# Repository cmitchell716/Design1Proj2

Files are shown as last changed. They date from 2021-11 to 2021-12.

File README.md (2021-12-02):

# Design1Proj2
This repository holds the source code for ECEN 4013 Group 2 Project 2.
The PCB and Case directories hold the files required for each component respectively. 
The headers directory have the modified header files in order to save memory.
Sketches hold all code run on the arduino, project_full is the final sketch used in the 
demonstration. All others test individual components or other related activities.

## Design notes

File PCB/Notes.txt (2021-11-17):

Notes on PCB

1. Cut bottom trace on Net (A1-Pad8) between via and Pin 8 on Arudino
2. Connected power switch between, Aux2 pin 1 and Pin 8 of Arudino

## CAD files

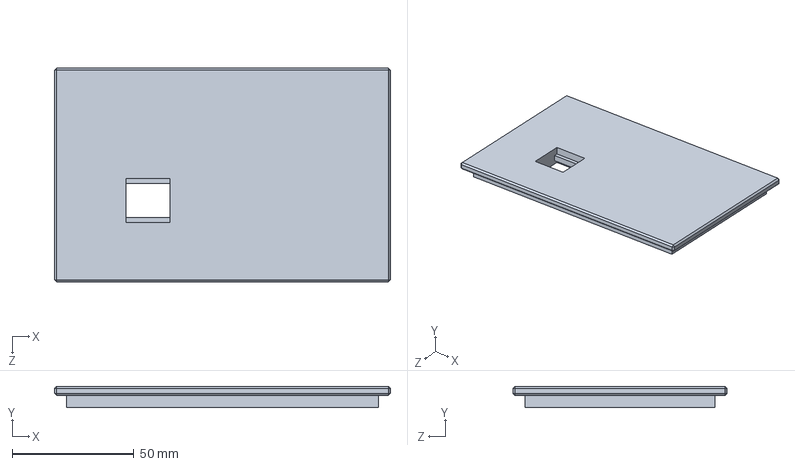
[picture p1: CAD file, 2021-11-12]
Case/Solid Works/main cover.sldprt
138.0 x 8.81 x 88.0 mm

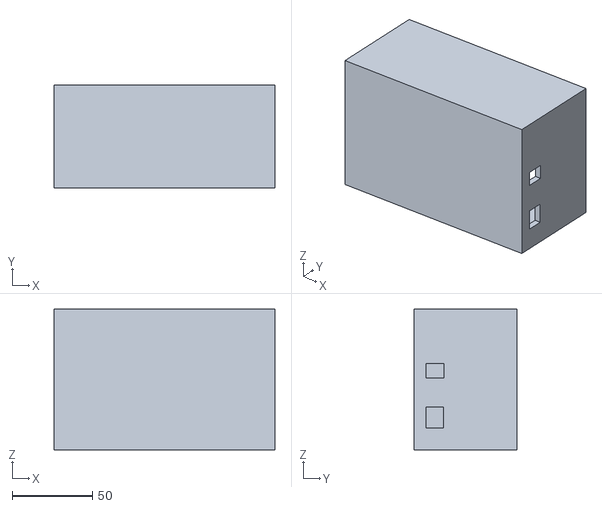
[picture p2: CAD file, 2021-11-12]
Case/STL Files/main.STL
138.0 x 64.1 x 88.0

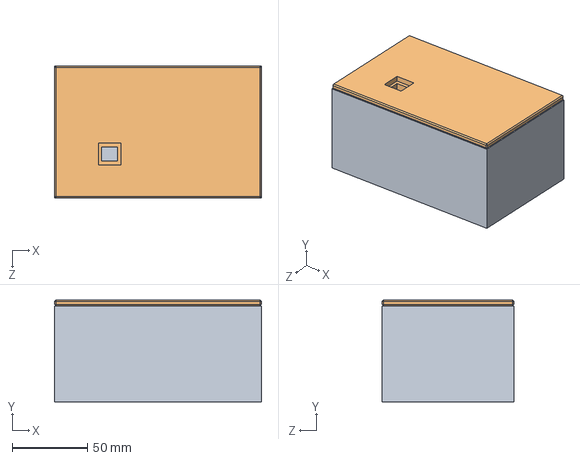
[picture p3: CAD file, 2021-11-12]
Case/Solid Works/simple box enclosure.sldasm
138.0 x 67.9 x 88.0 mm
main
main cover

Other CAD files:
Case/Solid Works/main.sldprt
Case/STL Files/main cover.STL

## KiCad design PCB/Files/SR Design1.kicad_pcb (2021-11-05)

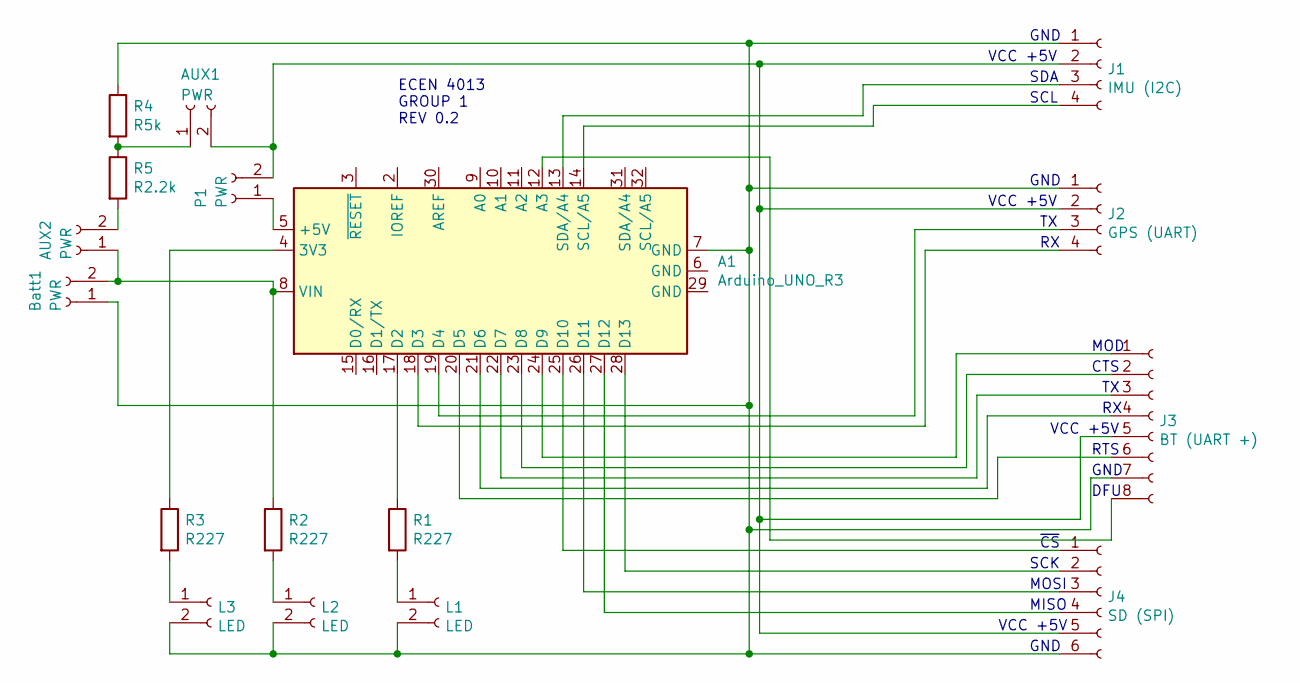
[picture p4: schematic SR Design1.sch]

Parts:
A1: Arduino_UNO_R3
AUX1, AUX2: PWR; SolderWire-0.1sqmm_1x02_P3.6mm_D0.4mm_OD1mm
Batt1: PWR; JST_XH_B2B-XH-A_1x02_P2.50mm_Vertical
J1: IMU (I2C); PinHeader_1x04_P2.00mm_Horizontal
J2: GPS (UART); PinHeader_1x04_P2.00mm_Horizontal
J3: BT (UART +); PinSocket_1x08_P2.54mm_Vertical
J4: SD (SPI); PinSocket_1x06_P2.54mm_Horizontal
L1, L2, L3: LED; SolderWire-0.1sqmm_1x02_P3.6mm_D0.4mm_OD1mm
P1: PWR; SolderWire-0.1sqmm_1x02_P3.6mm_D0.4mm_OD1mm
R1, R2, R3: R227; R_Axial_DIN0207_L6.3mm_D2.5mm_P10.16mm_Horizontal
R4: R5k; R_Axial_DIN0207_L6.3mm_D2.5mm_P10.16mm_Horizontal
R5: R2.2k; R_Axial_DIN0207_L6.3mm_D2.5mm_P10.16mm_Horizontal

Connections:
unnamed: A1.4 (3V3), R3.1
unnamed: A1.5 (+5V), P1.1
unnamed: A1.7 (GND), Batt1.1, J1.1, J2.1, J3.7, J4.6, L1.2, L2.2, L3.2, R4.1
unnamed: A1.8 (VIN), AUX2.1, Batt1.2, R2.1
unnamed: A1.12 (A3), J3.8
unnamed: A1.13 (SDA/A4), J1.3
unnamed: A1.14 (SCL/A5), J1.4
unnamed: A1.17 (D2), R1.1
unnamed: A1.18 (D3), J2.4
unnamed: A1.19 (D4), J2.3
unnamed: A1.20 (D5), J3.6
unnamed: A1.21 (D6), J3.4
unnamed: A1.22 (D7), J3.3
unnamed: A1.23 (D8), J3.2
unnamed: A1.24 (D9), J3.1
unnamed: A1.25 (D10), J4.1
unnamed: A1.26 (D11), J4.3
unnamed: A1.27 (D12), J4.4
unnamed: A1.28 (D13), J4.2
unnamed: AUX1.1, R4.2, R5.1
unnamed: AUX1.2, J1.2, J2.2, J3.5, J4.5, P1.2
unnamed: AUX2.2, R5.2
unnamed: L1.1, R1.2
unnamed: L2.1, R2.2
unnamed: L3.1, R3.2

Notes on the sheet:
GND
VCC +5V
SDA
SCL
SCK
MOSI
MISO
~CS
ECEN 4013 GROUP 1 REV 0.2
RTS
CTS
MOD
DFU

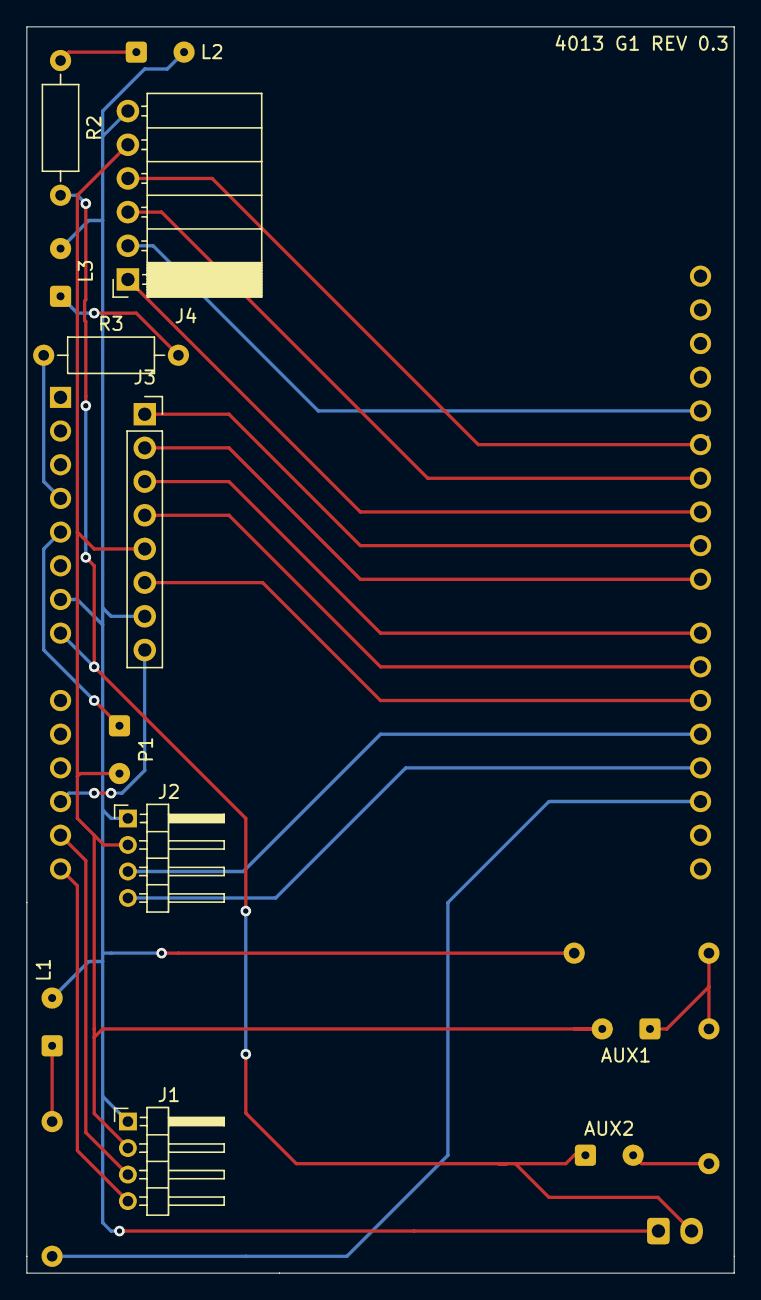
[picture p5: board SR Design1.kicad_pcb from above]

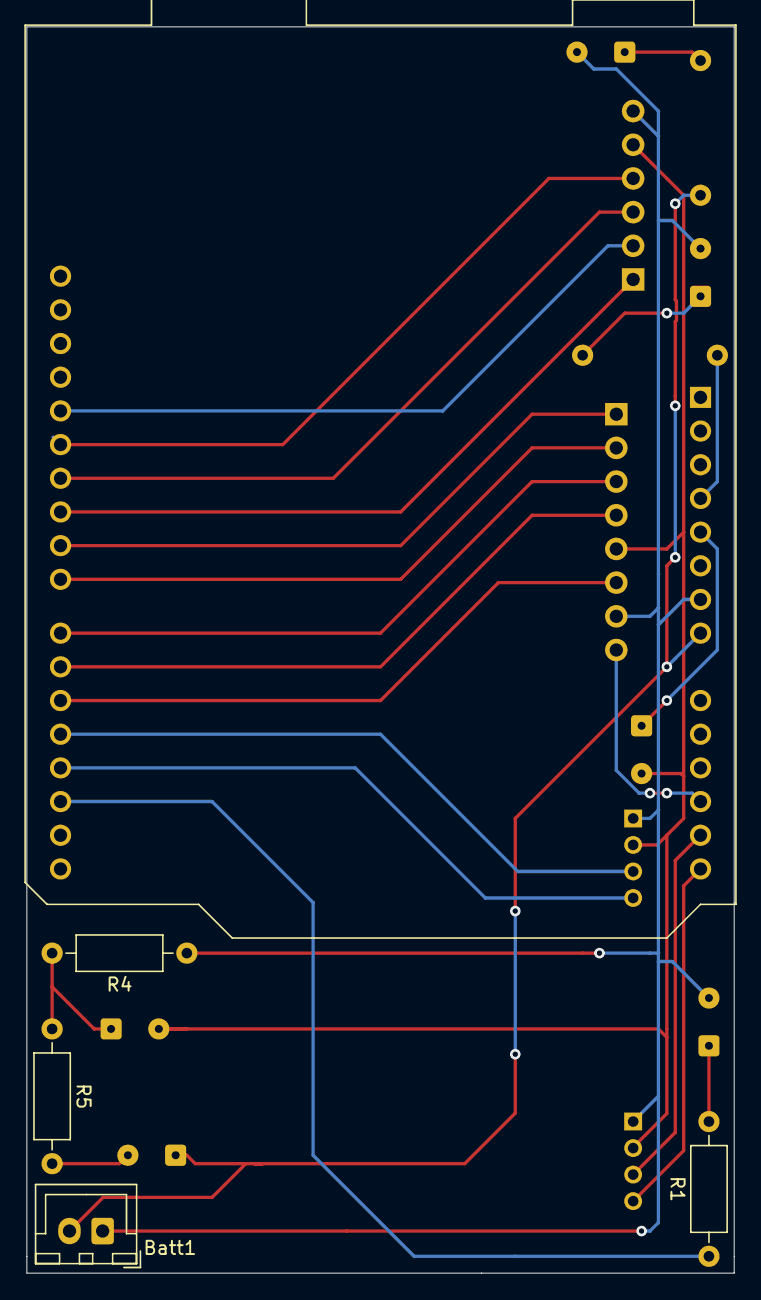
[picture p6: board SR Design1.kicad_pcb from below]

Board: 2 copper layers, 53.3 x 94.0 mm, 17 parts (5 on the bottom side), 25 nets.

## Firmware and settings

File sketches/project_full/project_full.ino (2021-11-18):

#include "C:\Users\cmitc\Documents\SeniorDesign1\Project2\repo\headers\MPU9250.h" //must change this line to location on your machine
#include <Wire.h>
#include <SoftwareSerial.h>
#include <TinyGPS_stripped.h>
#include <SPI.h>
#include <SdFat.h>
#include "Adafruit_BLE.h"
#include "Adafruit_BluefruitLE_UART.h"


TinyGPS gps;
SoftwareSerial ss(3, 4);
MPU9250 mpu;
SdFat sd;
SdFile myFile;
SoftwareSerial bluefruitSS = SoftwareSerial(7, 6);
Adafruit_BluefruitLE_UART ble(bluefruitSS, 9, 8, -1);
boolean newGPS = false;
boolean newIMU = false;
boolean SDavailable = false;
short printBle = 5;
boolean GPSlock = false;
unsigned long outputTimer;
const char filename[] = "out.csv"; 


void setup() {
  Serial.begin(9600);
  ss.begin(9600);
  Wire.begin();
  delay(2000);
  pinMode(2, OUTPUT);

  if (mpu.setup(0x68)) {  
    //mpu.setAccBias(36.19, 3.86, 54.43);
    //mpu.setGyroBias(-1.20, 1.95, -0.08);
    //mpu.setMagBias(128.27, -144.56, -176.65);
    //mpu.setMagScale(1.18, 1.03, 0.85);
    //mpu.setMagneticDeclination(3.08);
   }
  

  SDavailable = sd.begin(10, SPI_HALF_SPEED);
  if(SDavailable){
    create_file();
  }
  
  if ( !ble.begin() )
  {
    Serial.println(F("Couldn't find Bluefruit, make sure it's in CoMmanD mode & check wiring?"));
  }
  else{
    ble.echo(false);
    ble.setMode(BLUEFRUIT_MODE_DATA);
  }
  
   //SDavailable = false;
  outputTimer = millis();
}

void loop() {
  
  if (mpu.available()) {
        mpu.update_accel_gyro();
        mpu.update_mag();
        newIMU = true;
  }
  

  ss.listen();
  for (unsigned long start = millis(); millis() - start < 5;)
  {
    while (ss.available())
    {
      char c = ss.read();
      if (gps.encode(c))  
        newGPS = true;
    }
  }

  if(GPSlock){
    digitalWrite(2, HIGH);
  }
  else digitalWrite(2, LOW);
  
  if((newIMU && newGPS) || (millis() - outputTimer > 2000)) {
    print_IMU_measurements();
    print_GPS_measurements();
    outputTimer = millis();
    if(printBle == 10){
      printBle = 0;
    }
    else printBle++;
    if(newGPS){
      GPSlock = true;
    }
    else GPSlock = false;
    newGPS = false;
    newIMU = false;
  }
  
}

void create_file(){
  if (myFile.open(filename, O_WRITE | O_CREAT | O_TRUNC)) {
    delay(100);
    myFile.println(F("\"AccX\",\"AccY\",\"AccZ\",\"MagX\",\"MagY\",\"MagZ\",\"GyrX\",\"GyrY\",\"GyrZ\",\"Lat\",\"Lon\",\"Alt\",\"Sat\""));
  }
  myFile.close();
}


void print_IMU_measurements() {
  if(newIMU){
    Serial.print(F("Acc XYZ: "));
    Serial.print(mpu.getAccX(), 2);
    Serial.print(F(", "));
    Serial.print(mpu.getAccY(), 2);
    Serial.print(F(", "));
    Serial.print(mpu.getAccZ(), 2);
    Serial.print(F("  "));
    Serial.print(F("Mag XYZ: "));
    Serial.print(mpu.getMagX(), 2);
    Serial.print(F(", "));
    Serial.print(mpu.getMagY(), 2);
    Serial.print(F(", "));
    Serial.print(mpu.getMagZ(), 2);
    Serial.print(F(", "));
    Serial.print(F("Gyro XYZ: "));
    Serial.print(mpu.getGyroX(), 2);
    Serial.print(F(", "));
    Serial.print(mpu.getGyroY(), 2);
    Serial.print(F(", "));
    Serial.println(mpu.getGyroZ(), 2);

    if(printBle == 10){
      ble.print(F("Acc XYZ: "));
      ble.print(mpu.getAccX(), 2);
      ble.print(F(", "));
      ble.print(mpu.getAccY(), 2);
      ble.print(F(", "));
      ble.print(mpu.getAccZ(), 2);
      ble.print(F("  "));
      ble.print(F("Mag XYZ: "));
      ble.print(mpu.getMagX(), 2);
      ble.print(F(", "));
      ble.print(mpu.getMagY(), 2);
      ble.print(F(", "));
      ble.print(mpu.getMagZ(), 2);
      ble.print(F(", "));
      ble.print(F("Gyro XYZ: "));
      ble.print(mpu.getGyroX(), 2);
      ble.print(F(", "));
      ble.print(mpu.getGyroY(), 2);
      ble.print(F(", "));
      ble.println(mpu.getGyroZ(), 2);
    }

    if(SDavailable){      
      myFile.open(filename, O_WRITE | O_AT_END);
      myFile.print(F("\""));
      myFile.print(mpu.getAccX(), 2);
      myFile.print(F("\",\""));
      myFile.print(mpu.getAccY(), 2);
      myFile.print(F("\",\""));
      myFile.print(mpu.getAccZ(), 2);
      myFile.print(F("\",\""));
      myFile.print(mpu.getMagX(), 2);
      myFile.print(F("\",\""));
      myFile.print(mpu.getMagY(), 2);
      myFile.print(F("\",\""));
      myFile.print(mpu.getMagZ(), 2);
      myFile.print(F("\",\""));
      myFile.print(mpu.getGyroX(), 2);
      myFile.print(F("\",\""));
      myFile.print(mpu.getGyroY(), 2);
      myFile.print(F("\",\""));
      myFile.print(mpu.getGyroZ(), 2);
      myFile.print(F("\",\""));
      myFile.close();     
    }
    
  }
  else{
    Serial.println(F("No IMU data"));
    if(printBle == 10){
      ble.println(F("No IMU data"));
    }
    if(SDavailable){      
      myFile.open(filename, O_WRITE | O_AT_END);
      myFile.print(F("\"N/D\",\"N/D\",\"N/D\",\"N/D\",\"N/D\",\"N/D\",\"N/D\",\"N/D\",\"N/D\","));
      myFile.close();     
    }    
  }    
}

void print_GPS_measurements() {
  if(newGPS){
    float flat, flon;
    int alt, sat;
    alt = gps.altitude();
    sat = gps.satellites();
    gps.f_get_position(&flat, &flon );
    Serial.print(F("LAT="));
    Serial.print(flat, 6);
    Serial.print(F(" LON="));
    Serial.print(flon, 6);
    Serial.print(F(" ALT="));
    Serial.print(alt);
    Serial.print(F(" SAT="));
    Serial.println(sat);
  
    
    if(printBle == 10){
      ble.print(F("LAT="));
      ble.print(flat, 6);
      ble.print(F(" LON="));
      ble.print(flon, 6);
      ble.print(F(" ALT="));
      ble.print(alt);
      ble.print(F(" SAT="));
      ble.println(sat);
    }
    

    if(SDavailable){     
      myFile.open(filename, O_WRITE | O_AT_END);
      myFile.print(flat, 6);
      myFile.print(F("\",\""));
      myFile.print(flon, 6); 
      myFile.print(F("\",\""));
      myFile.print(alt);
      myFile.print(F("\",\""));
      myFile.print(sat);
      myFile.println(F("\""));
      myFile.close();      
    }
  }
  else{
    Serial.println(F("No GPS data"));
    if(printBle == 10){
      ble.println(F("No GPS data"));
    }       
    if(SDavailable){      
      myFile.open(filename, O_WRITE | O_AT_END);
      myFile.println(F("\"N/D\",\"N/D\",\"N/D\",\"N/D\""));
      myFile.close();      
    }  
  } 
}

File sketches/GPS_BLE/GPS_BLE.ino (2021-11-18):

#include <SoftwareSerial.h>
#include <TinyGPS_stripped.h>
#include "Adafruit_BLE.h"
#include "Adafruit_BluefruitLE_UART.h"
#include <SPI.h>
#include <SdFat.h>

TinyGPS gps;
SoftwareSerial ss(3, 4);
SoftwareSerial bluefruitSS = SoftwareSerial(7, 6);
Adafruit_BluefruitLE_UART ble(bluefruitSS, 9, 8, -1);
SdFat sd;
SdFile myFile;
boolean newGPS = false;
boolean SDavailable = false;
char filename[] = "testingcsv.csv"; 

void setup() {
  Serial.begin(9600);
  ss.begin(9600);
  delay(2000);
  pinMode(2, OUTPUT);

  if ( !ble.begin() )
  {
    Serial.println(F("Couldn't find Bluefruit, make sure it's in CoMmanD mode & check wiring?"));
  }
  else{
    ble.echo(false);
    ble.setMode(BLUEFRUIT_MODE_DATA);
  }
  
  SDavailable = sd.begin(10, SPI_HALF_SPEED);
  if(SDavailable){
    create_file();
  }
  digitalWrite(2, HIGH);
}

void loop() {
  ss.listen();
  for (unsigned long start = millis(); millis() - start < 20;)
  {
    while (ss.available())
    {
      char c = ss.read();
      if (gps.encode(c))  
        newGPS = true;
    }
  }

  if(newGPS){
    print_GPS_measurements();
  }
}

void create_file(){
  if (myFile.open(filename, O_WRITE | O_CREAT | O_TRUNC)) {
    delay(100);
    myFile.println(F("\"AccX\",\"AccY\",\"AccZ\",\"MagX\",\"MagY\",\"MagZ\",\"GyrX\",\"GyrY\",\"GyrZ\",\"Lat\",\"Lon\",\"Alt\",\"Sat\""));
  }
  myFile.close();
}

void print_GPS_measurements() {
  if(newGPS){
    float flat, flon;
    gps.f_get_position(&flat, &flon );
    Serial.print(F("LAT="));
    Serial.print(flat == TinyGPS::GPS_INVALID_F_ANGLE ? 0.0 : flat, 6);
    Serial.print(F(" LON="));
    Serial.print(flon == TinyGPS::GPS_INVALID_F_ANGLE ? 0.0 : flon, 6);
    Serial.print(F(" ALT="));
    Serial.print(gps.altitude() == TinyGPS::GPS_INVALID_ALTITUDE ? 0 : gps.altitude());
    Serial.print(F(" SAT="));
    Serial.println(gps.satellites() == TinyGPS::GPS_INVALID_SATELLITES ? 0 : gps.satellites());
  

    ble.print(F("LAT="));
    ble.print(flat == TinyGPS::GPS_INVALID_F_ANGLE ? 0.0 : flat, 6);
    ble.print(F(" LON="));
    ble.print(flon == TinyGPS::GPS_INVALID_F_ANGLE ? 0.0 : flon, 6);
    ble.print(F(" ALT="));
    ble.print(gps.altitude() == TinyGPS::GPS_INVALID_ALTITUDE ? 0 : gps.altitude());
    ble.print(F(" SAT="));
    ble.println(gps.satellites() == TinyGPS::GPS_INVALID_SATELLITES ? 0 : gps.satellites());

    if(SDavailable){     
      myFile.open(filename, O_WRITE | O_AT_END);
      myFile.print(flat == TinyGPS::GPS_INVALID_F_ANGLE ? 0.0 : flat, 6);
      myFile.print(F("\",\""));
      myFile.print(flon == TinyGPS::GPS_INVALID_F_ANGLE ? 0.0 : flon, 6); 
      myFile.print(F("\",\""));
      myFile.print(gps.altitude() == TinyGPS::GPS_INVALID_ALTITUDE ? 0 : gps.altitude());
      myFile.print(F("\",\""));
      myFile.print(gps.satellites() == TinyGPS::GPS_INVALID_SATELLITES ? 0 : gps.satellites());
      myFile.println(F("\""));
      myFile.close();
    }
    
  }
  else{
    Serial.println(F("No GPS data"));
    ble.println(F("No GPS data")); 
  }
} 

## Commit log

2021-11-03 Adding PCB Files
    Adds
    - fp-info-cache
    - Sr Design 1-cache.lib
    - Sr Design 1.kicad_pcb
    - Sr Design 1.kicad_pcb-bak
    - Sr Design 1.net
    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
    [SR Design1.kicad_pcb, SR Design1.sch]
2021-11-03 IMU test, configuration, and I2C connection check
2021-11-03 Updated PCB to REV 0.3
    Updated all PCB files previously added. These should be updated to Rev 0.3 with new BT module and alternative power circuit. Board size not changed.
    [SR Design1.kicad_pcb, SR Design1.sch]
2021-11-03 Updated Schmatic
    Updated Schematic to the correct revision.
    [SR Design1.sch]
2021-11-04 Adding finished PCB and Gerber Files
    Added all Gerber files not in .zip form. Also updated PCB to newest version.
    [SR Design1-B_Cu.gbr, SR Design1-B_Mask.gbr, SR Design1-B_SilkS.gbr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]
2021-11-06 reduced storage space of IMU and fixed magnetometer
    [IMU_test.ino, input_combined.ino]
2021-11-12 Adding Case Files
    Adding SolidWorks files and STL files of our case.
    [main cover.STL, main cover.sldprt, main.STL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]
2021-11-16 final code fingers crossed
2021-11-17 Moved KiCad Files
    Moved KiCad Files and added a .txt file illustrating new wiring for power.
    [SR Design1.kicad_pcb, SR Design1.sch]
